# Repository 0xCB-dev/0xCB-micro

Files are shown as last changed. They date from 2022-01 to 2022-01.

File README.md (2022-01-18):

# 0xcb-micro
## 1% - 65% keyboard controller with RGB underglow and a backlight driver

Licence | OSHWA
:-------------------------:|:-------------------------:
 | (https://certification.oshwa.org/de000115.html)

#### Flashing

* `qmk clone`
* `cd qmk_firmware`
* `export LTO=Y`
* To go to bootloader hold the ESC key (row0 col0 / the key on the PCB) while plugging in (or short RST from the ISP header to GND).
* `make 0xcb/micro:via:flash`

### Assembly:

You can use the [humanpnp](https://files.0xcb.dev/0xCB-micro/humanpnp.html) to easily place components.

### PCB:
KiCad 6 stable

[Schematic](https://github.com/0xCB-dev/0xcb-micro/blob/main/rev1.0/micro.pdf)

Top | Bottom
:-------------------------:|:-------------------------:
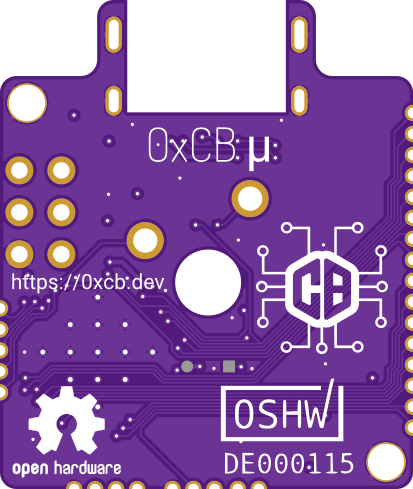
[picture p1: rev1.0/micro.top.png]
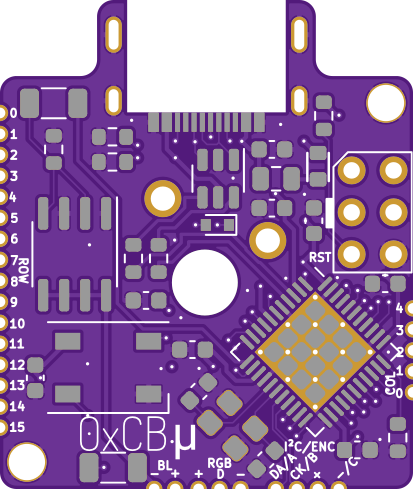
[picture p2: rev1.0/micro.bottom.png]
  |  

#### BOM:
| References | Value | Quantity |Part Nb. |
|---|---|---|---|
| C2, C3, C4, C5, C10 | 100n | 5 |C478888 |
| C6, C9 | 1u | 2 |C29936 |
| C7, C8 | 22p | 2 |C85969 |
| C1 | 10u | 1 |C85713 |
| R5, R6, R8 | 10k | 3 |C98220 |
| R1, R2 | 5.1k | 2 |C23186 |
| R3, R4 | 22 | 2 |C174301 |
| R7, R9 | 330 | 2 |C104763 |
| D1 | 1N4148WT | 1 |C511874 |
| D2 | WS2812B | 1 |C114586 |
| U2 | ATMEGA32U4  | 1 |ATMEGA32U4RC-MU-ND|
| U1 | USBLC6-2SC6 | 1 |C7519 |
| Y1 | 16MHz | 1 |C389842 |
| F1 | 1A | 1 |C369150 |
| FB1 | 600R | 1 |C74330 |
| Q1 | FDS9926A | 1 |C693202 |
| J1 | USB | 1 |C168688 |

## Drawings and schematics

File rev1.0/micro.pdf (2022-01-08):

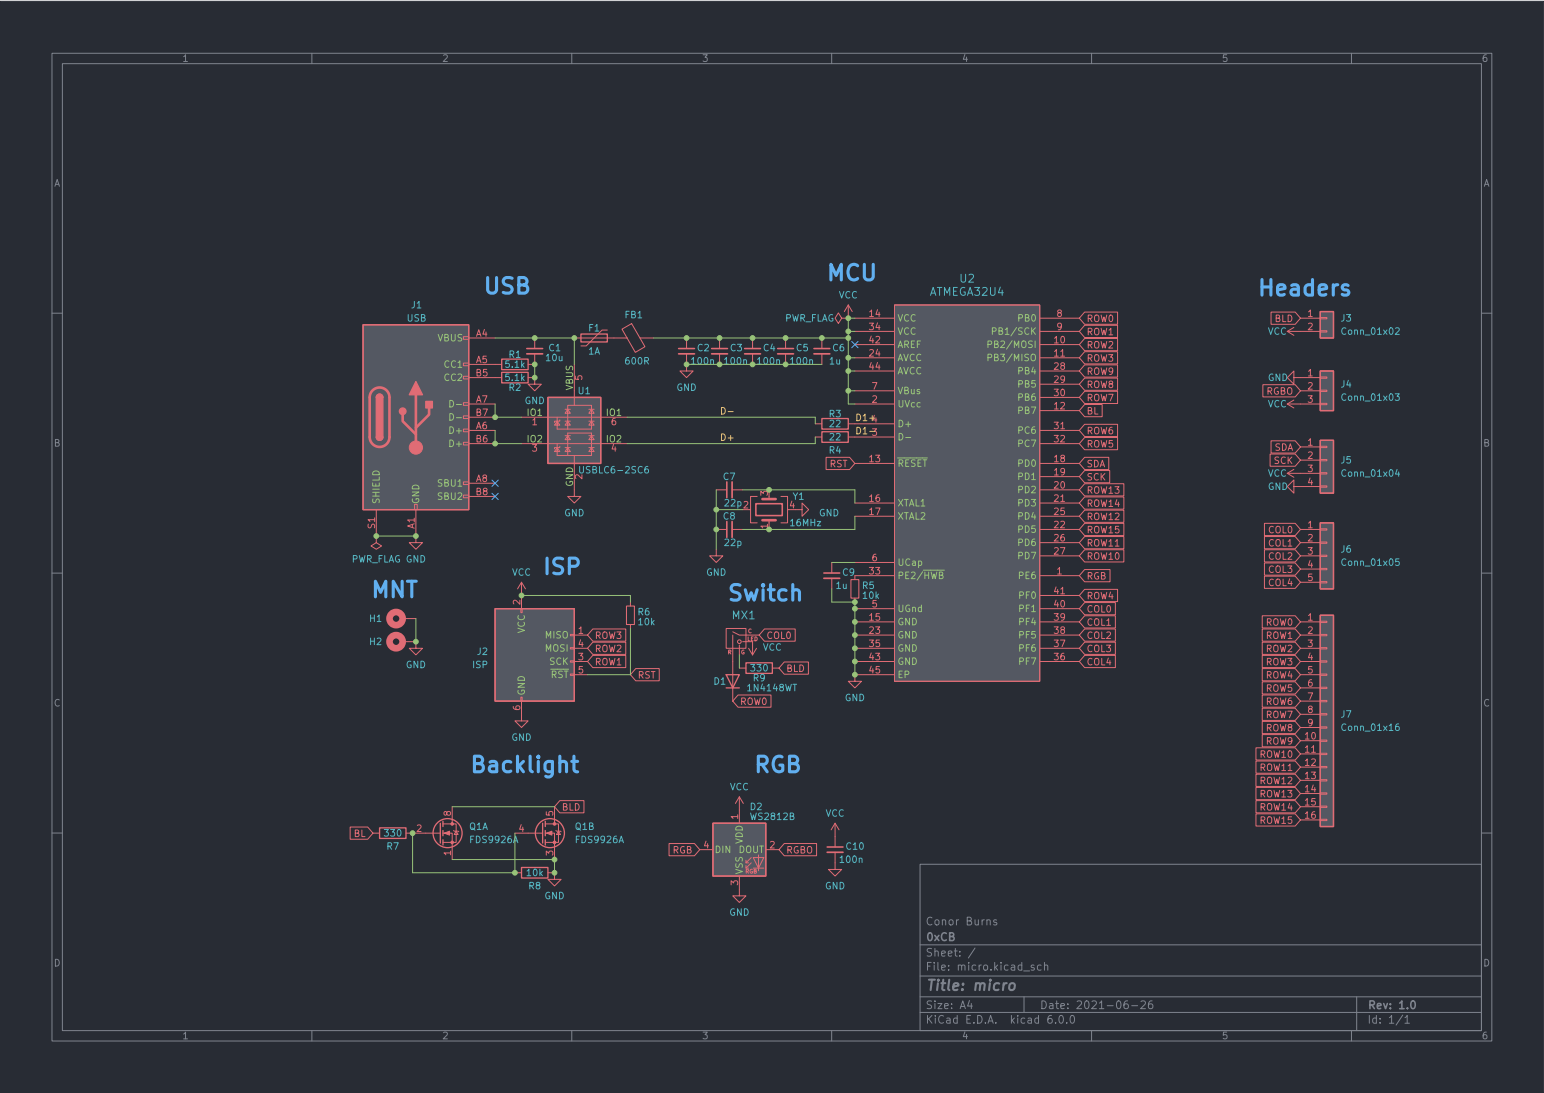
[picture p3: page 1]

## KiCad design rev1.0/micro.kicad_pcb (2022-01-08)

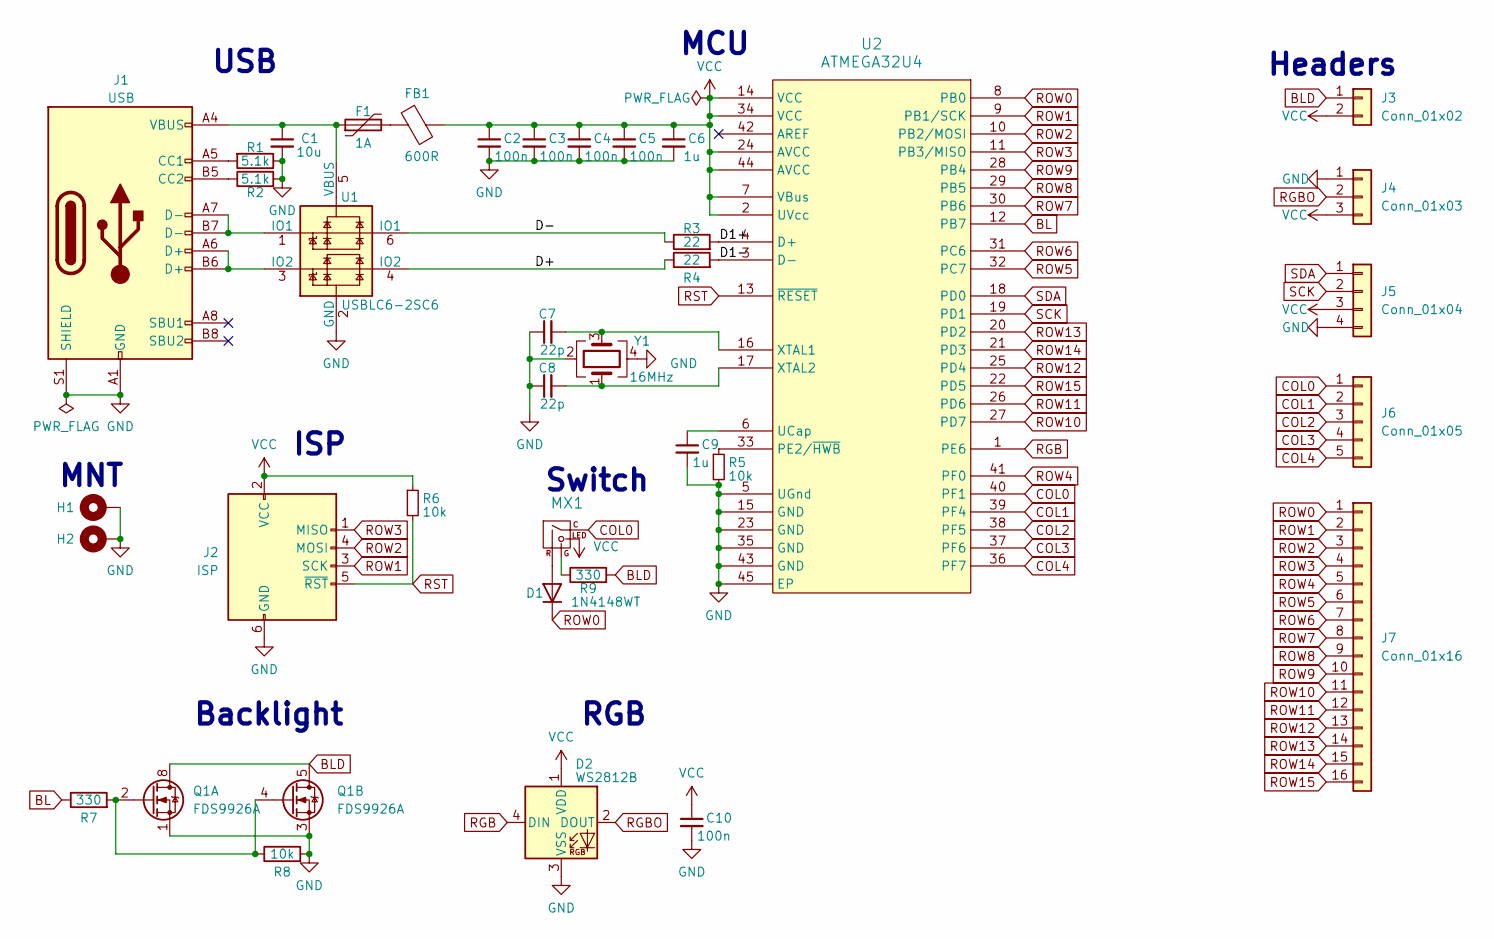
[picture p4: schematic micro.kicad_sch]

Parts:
C1: 10u; C_0603_1608Metric
C2, C3, C4, C5, C10: 100n; C_0603_1608Metric
C6, C9: 1u; C_0603_1608Metric
C7, C8: 22p; C_0603_1608Metric
D1: 1N4148WT; D_SOD-523
D2: WS2812B; LED_WS2812B_PLCC4_5.0x5.0mm_P3.2mm
F1: 1A; Fuse_0805_2012Metric
FB1: 600R; Ferrite_Bead_0603
H1, H2: MountingHole_Pad; MountingHole_2.2mm_M2_DIN965_Pad_TopBottom_SMOL
J1: USB; HRO-TYPE-C-31-M-13
J2: ISP; AVR_PROG_2.54_THT
J3: Conn_01x02; PinHeader_1x02_P1.27mm_Vertical
J4: Conn_01x03; PinHeader_1x03_P1.27mm_Vertical
J5: Conn_01x04; PinHeader_1x04_P1.27mm_Vertical
J6: Conn_01x05; PinHeader_1x05_P1.27mm_Vertical
J7: Conn_01x16; PinHeader_1x16_P1.27mm_Vertical
MX1: MX-LED; MXOnly-1U
Q1: FDS9926A; SOIC-8_3.9x4.9mm_P1.27mm
R1, R2: 5.1k; R_0603_1608Metric
R3, R4: 22; R_0603_1608Metric
R5, R6, R8: 10k; R_0603_1608Metric
R7, R9: 330; R_1206_3216Metric
U1: USBLC6-2SC6; SOT-23-6
U2: ATMEGA32U4; QFN-44-1EP_7x7mm_P0.5mm_EP5.2x5.2mm_ThermalVias
Y1: 16MHz; Crystal_SMD_3225-4Pin_3.2x2.5mm

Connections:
/D1+: R3.2, U2.4 (D+)
/D1-: R4.2, U2.3 (D-)
/D+: R4.1, U1.4 (IO2)
/D-: R3.1, U1.6 (IO1)
BL: R7.1, U2.12 (PB7)
BLD: J3.1, Q1.5 (D2), Q1.6 (D2), Q1.7 (D1), Q1.8 (D1), R9.2
COL0: J6.1, MX1.1 (COL), U2.40 (PF1)
COL1: J6.2, U2.39 (PF4)
COL2: J6.3, U2.38 (PF5)
COL3: J6.4, U2.37 (PF6)
COL4: J6.5, U2.36 (PF7)
GND: C1.2, C2.2, C3.2, C4.2, C5.2, C6.2, C7.1, C8.1, C9.2, C10.2, D2.3 (VSS), H1.1, H2.1, J1.A1 (GND), J1.A12 (GND), J1.B1 (GND), J1.B12 (GND), J1.S1 (SHIELD), J2.6 (GND), J4.1, J5.4, Q1.1 (S1), Q1.3 (S2), R1.1, R2.2, R5.2, R8.2, U1.2 (GND), U2.5 (UGnd), U2.15 (GND), U2.23 (GND), U2.35 (GND), U2.43 (GND), U2.45 (EP), Y1.2, Y1.4
unnamed: C1.1, F1.1, J1.A4 (VBUS), J1.A9 (VBUS), J1.B4 (VBUS), J1.B9 (VBUS), U1.5 (VBUS)
unnamed: C7.2, U2.16 (XTAL1), Y1.3
unnamed: C8.2, U2.17 (XTAL2), Y1.1
unnamed: C9.1, U2.6 (UCap)
unnamed: D1.2 (A), MX1.2 (ROW)
unnamed: F1.2, FB1.1
unnamed: J1.A5 (CC1), R1.2
unnamed: J1.A6 (D+), J1.B6 (D+), U1.3 (IO2)
unnamed: J1.A7 (D-), J1.B7 (D-), U1.1 (IO1)
unnamed: J1.B5 (CC2), R2.1
unnamed: MX1.4 (LEDGND), R9.1
unnamed: Q1.2 (G1), Q1.4 (G2), R7.2, R8.1
unnamed: R5.1, U2.33 (PE2/~HWB)
RGB: D2.4 (DIN), U2.1 (PE6)
RGBO: D2.2 (DOUT), J4.2
ROW0: D1.1 (K), J7.1, U2.8 (PB0)
ROW1: J2.3 (SCK), J7.2, U2.9 (PB1/SCK)
ROW2: J2.4 (MOSI), J7.3, U2.10 (PB2/MOSI)
ROW3: J2.1 (MISO), J7.4, U2.11 (PB3/MISO)
ROW4: J7.5, U2.41 (PF0)
ROW5: J7.6, U2.32 (PC7)
ROW6: J7.7, U2.31 (PC6)
ROW7: J7.8, U2.30 (PB6)
ROW8: J7.9, U2.29 (PB5)
ROW9: J7.10, U2.28 (PB4)
ROW10: J7.11, U2.27 (PD7)
ROW11: J7.12, U2.26 (PD6)
ROW12: J7.13, U2.25 (PD4)
ROW13: J7.14, U2.20 (PD2)
ROW14: J7.15, U2.21 (PD3)
ROW15: J7.16, U2.22 (PD5)
RST: J2.5 (~RST), R6.2, U2.13 (~RESET)
SCK: J5.2, U2.19 (PD1)
SDA: J5.1, U2.18 (PD0)
VCC: C2.1, C3.1, C4.1, C5.1, C6.1, C10.1, D2.1 (VDD), FB1.2, J2.2 (VCC), J3.2, J4.3, J5.3, MX1.3 (LED), R6.1, U2.2 (UVcc), U2.7 (VBus), U2.14 (VCC), U2.24 (AVCC), U2.34 (VCC), U2.44 (AVCC)

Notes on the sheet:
Switch
ISP
Backlight
MNT
RGB
Headers
USB
MCU

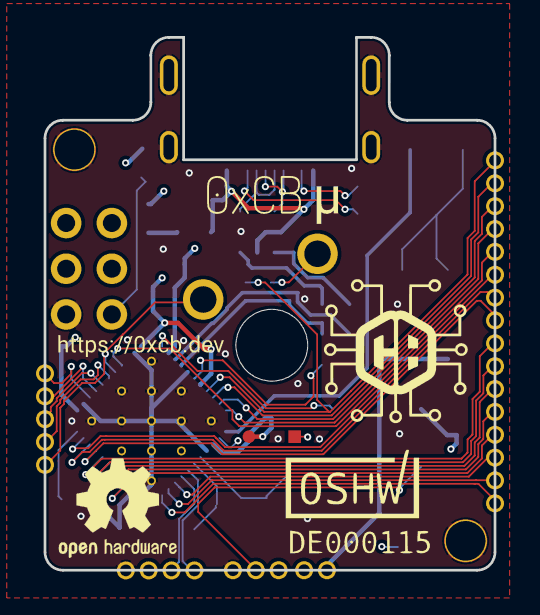
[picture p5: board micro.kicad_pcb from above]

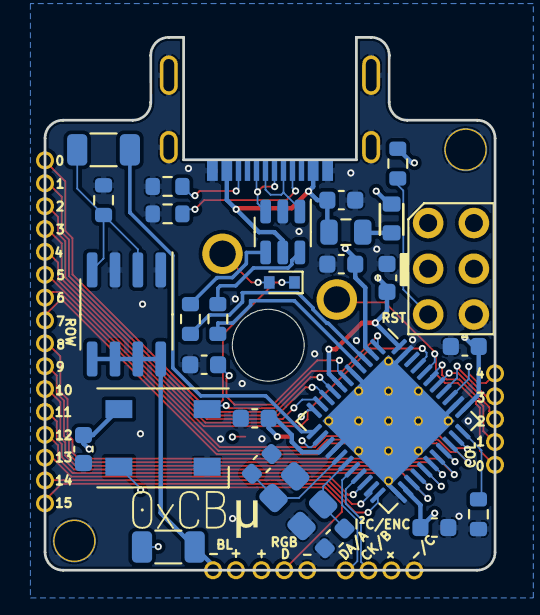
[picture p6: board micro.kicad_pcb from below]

Board: 4 copper layers, 25.0 x 29.6 mm, 42 parts (35 on the bottom side), 47 nets.

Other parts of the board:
0xCB: G***; svg2mod
micro: G***; svg2mod
svg2mod, svg2mod#2, svg2mod#3: G***; svg2mod
